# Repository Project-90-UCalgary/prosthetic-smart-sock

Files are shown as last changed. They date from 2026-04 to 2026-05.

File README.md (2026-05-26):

# prosthetic-smart-sock
Creating a smart sock for lower limb prosthetics to create more comfortable and constant fitting

## MATLAB 3D model

Run `MATLABWiFiV1.m` for the live GUI. The limb model is your CAD STL (`models/leg.stl`) with **16 sensors** on the calf sock patch. Change `SENSOR_SEED` to reshuffle sensor sites; replace `models/leg.stl` to update geometry.

## MindFuel Demo

See **`MindFuel Demo/`** for a self-contained demo package (ESP32 firmware, MATLAB GUI, wiring tutorial, and `models/leg.stl`).

## Setup

See `SETUP.md` for full replication steps (hardware, firmware, and MATLAB workflow).

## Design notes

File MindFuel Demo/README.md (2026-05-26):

# MindFuel Demo

Self-contained package for demonstrating the **Project 90 prosthetic smart sock** telemetry stack: 16-channel pressure sensing through a CD74HC4067 multiplexer, ESP32 firmware, and a MATLAB live visualization GUI with a 3D leg heatmap.

Part of the [prosthetic-smart-sock](https://github.com/Project-90-UCalgary/prosthetic-smart-sock) repository.

## What this iteration does

### Hardware

- **16 analog channels** (mux c0–c15) read through a **CD74HC4067** 16:1 analog multiplexer.
- **ESP32** selects mux channels, reads ADC values (12-bit, 0–4095), and exposes them to MATLAB.
- Typical sensor wiring: more mechanical pressure → **lower** ADC reading (FSR / divider style). The MATLAB GUI inverts this so **higher displayed values = more pressure**.

### Firmware (ESP32)

Two sketches are included under `firmware/`:

| Sketch | Use case |
|---|---|
| `ESP32_Wifi_Station_Test` | **Recommended for demos.** ESP32 joins Wi‑Fi (or starts SoftAP) and serves JSON at `/mux-all`. Built-in web dashboard at `/`. |
| `ESP32_Serial_Mux_16ch` | USB serial at **9600 baud** — one line per frame, 16 fixed-width ADC fields for MATLAB **Serial** mode. |

Both sketches share the same mux pin map (see `TUTORIAL.md`).

### MATLAB GUI (`matlab/MATLABWiFiV1.m`)

Run `runDemo` or `MATLABWiFiV1` from the `matlab/` folder.

The GUI provides:

- **3D heatmap** on a CAD leg mesh (`models/leg.stl`) with **16 sensor sites** on the calf/stump patch.
- **Live bar chart** and **10-second rolling history** for all 16 channels (M0–M15).
- **Dark theme** with light control sliders.
- **Four input modes:**
  1. **Random** — simulated signals for testing without hardware.
  2. **Sliders** — manual channel levels via on-screen sliders.
  3. **Serial** — live data from `ESP32_Serial_Mux_16ch` over USB.
  4. **WiFi AP (/mux-all)** — polls ESP32 JSON (default URL: `http://192.168.4.1/mux-all` when using SoftAP).

Heatmap behavior (current tuning):

- Local Gaussian blobs per sensor (`SIGMA_HEAT_MM = 20` mm).
- Max sensor value maps to the top of the color scale (yellow/white on the `hot` colormap).
- Fixed colorbar **0–100** with ticks at 0, 25, 50, 75, 100.

### Supporting files

| File | Role |
|---|---|
| `loadProstheticStlMesh.m` | Loads `leg.stl`, places 16 deterministic sensor sites along the stump axis. |
| `models/leg.stl` | Project 90 leg assembly mesh (mm units, native CAD orientation). |
| `runDemo.m` | Convenience launcher — changes to this folder and opens the GUI. |

## Quick start

1. Wire the mux and sensors (see **`TUTORIAL.md`**).
2. Flash **`firmware/ESP32_Wifi_Station_Test`** (set Wi‑Fi credentials or use SoftAP).
3. In MATLAB:
   ```matlab
   cd('MindFuel Demo/matlab')
   runDemo
   ```
4. Set **Input Mode** to **WiFi AP (/mux-all)** and confirm `WIFI_URL` in the script matches your ESP32 IP (e.g. `http://192.168.4.1/mux-all` for SoftAP).

For step-by-step wiring, flashing, and network setup, see **`TUTORIAL.md`**.

## Configuration knobs

In `MATLABWiFiV1.m` (top of file):

| Setting | Default | Purpose |
|---|---|---|
| `WIFI_URL` | `http://192.168.4.1/mux-all` | ESP32 JSON endpoint |
| `SENSOR_SEED` | `42` | Reproducible sensor placement on the mesh |
| `SIGMA_HEAT_MM` | `20` | Heat blob radius on the 3D surface |
| `SERIAL_INVERT_ADC` | `true` | Map lower ADC → higher display value |
| `CAL_ADC_MIN` / `CAL_ADC_MAX` | per-channel | Optional per-sensor calibration |

## Security note

Do **not** commit real Wi‑Fi passwords. Use placeholders in firmware and share credentials privately for demos.

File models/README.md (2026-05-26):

# Limb CAD mesh

- **`leg.stl`** — Project 90 prosthetic leg assembly (`May Prosthetic Assembyl.stl`), mm units.
- The loader keeps the **native CAD orientation** (no automatic re-rotation).
- To update: copy your export over this file, or set `LIMB_STL` in `MATLABWiFiV1.m`.

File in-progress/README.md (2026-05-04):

# In-progress (weekday work — not yet team-reviewed)

This folder holds **work-in-progress** versions of the GUI and ESP32 firmware. The **same paths at the repository root** and under `firmware/` stay on the **mainline / Saturday baseline** the team already agreed on.

| Path (mirrors repo) | Notes |
|---|---|
| `P90_Simulated_MLAB.m` | Weekday iteration: 5ch, 30s history, wall-clock axis, etc. |
| `ESP32_Wifi_Station_Test.ino` | Station + SoftAP + `/c1-c5` and related |
| `firmware/P90ArduinoMux.ino` | AP mode + serial + JSON |
| `firmware/ESP32_Wifi_Station_Test.ino` | |
| `firmware/README.txt` | |

**How to use:** Copy or diff these files over the root copies when promoting after Saturday sign-off, or run MATLAB/Arduino from this folder path until then.

**Do not** treat this tree as the default for new contributors — use root + `firmware/` for the stable project layout until the team merges the WIP.

## Weekly update log (in-progress)

GitHub’s README renderer usually **ignores** `<colgroup>` / `%` widths on HTML tables, so a two-column “Week & dates | Highlights” layout stays squeezed on the left. This section uses **headings + bullets** instead so dates stay on one line.

When you add a week: copy the `### …` block below, change the dates, and edit the highlights.

### Mon `2026-05-04`

**Highlights**

5 FSR channels; WiFi/JSON `c1`–`c5` + matching firmware; display 0–100; `turbo` colormap + linear heat scaling; 30 s history with **wall-clock** time axis; non-overlapping controls + more random-mode diversity; `in-progress/` split from mainline on GitHub.

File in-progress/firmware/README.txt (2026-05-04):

ESP32 sketches for P90 mux + WiFi JSON endpoints.

Before flashing: edit YOUR_* placeholders in the .ino files for SSID and password.
See repo root README.md for project context.

Included:
- P90ArduinoMux.ino — multiplexer scan + SoftAP + HTTP /c1-c4 (mux ch 1–4)
- ESP32_Wifi_Station_Test.ino — STA + SoftAP fallback + diagnostics

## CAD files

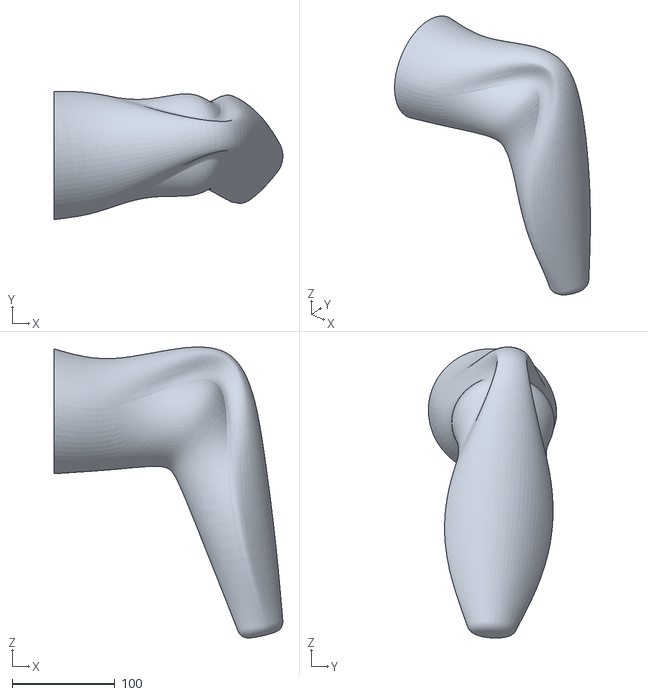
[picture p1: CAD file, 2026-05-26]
MindFuel Demo/matlab/models/leg.stl
223.0 x 125.0 x 283.8

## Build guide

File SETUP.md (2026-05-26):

# Project 90 Smart Sock Setup Guide

This guide explains how to set up the ESP32 firmware and MATLAB script so someone else can replicate the project.

## 1) Requirements

- ESP32 development board
- CD74HC4067 (16-channel analog multiplexer) or equivalent
- Pressure/analog sensors connected to the mux channels
- Jumper wires and breadboard
- USB cable for ESP32
- Arduino IDE (with ESP32 board support installed)
- MATLAB (for running the desktop-side script)
- A Wi-Fi network for STA mode (optional if using SoftAP fallback)

## 2) Wiring (based on current firmware constants)

The sketch `ESP32_Wifi_Station_Test.ino` currently uses:

- `LED_PIN = 4`
- `MUX_EN_PIN = 2`
- `MUX_S0_PIN = 12`
- `MUX_S1_PIN = 14`
- `MUX_S2_PIN = 27`
- `MUX_S3_PIN = 26`
- `MUX_SIG_PIN = 34` (ADC input)

Wire your mux select lines and signal output to these ESP32 pins, or update the constants in the sketch to match your hardware.

## 3) Configure and Flash ESP32 Firmware

1. Open `ESP32_Wifi_Station_Test.ino` in Arduino IDE.
2. Install required libraries if prompted (`WiFi.h` and `WebServer.h` come with ESP32 core).
3. Set network credentials before flashing:
   - `WIFI_SSID`
   - `WIFI_PASSWORD`
   - Optional AP fallback: `AP_SSID`, `AP_PASSWORD`
4. Select the correct ESP32 board and COM port.
5. Upload the sketch.
6. Open Serial Monitor at `115200` baud and confirm startup messages.

## 4) Validate ESP32 Server

After boot, the board will:

- Try to join Wi-Fi in station mode first.
- If station connection fails, start its own SoftAP network.

From a browser on the same network, open:

- `http://<esp32-ip>/` (dashboard)
- `http://<esp32-ip>/status`
- `http://<esp32-ip>/c0-c3`
- `http://<esp32-ip>/mux-all`

If using SoftAP fallback, connect your computer to the ESP32 AP SSID first, then use the AP IP shown in Serial Monitor.

## 5) Run MATLAB Integration

Primary script: **`MATLABWiFiV1.m`**

- 3D model: CAD assembly STL (`models/leg.stl`, copied from your export)
- **16 sensors** (mux c0–c15) placed randomly on the **calf sock patch** (mesh heuristic)
- Reshuffle sites: change `SENSOR_SEED` near the top of the script
- Replace mesh: overwrite `models/leg.stl` or set `LIMB_STL` in the script
- Loader: `loadProstheticStlMesh.m`

Legacy: `buildProstheticLimbMesh.m` (procedural fallback), `P90_Simulated_MLAB.m` (older GUI)

Typical workflow:

1. Open MATLAB and run `MATLABWiFiV1`.
2. Set `WIFI_URL` if using WiFi mode (ESP32 IP + `/mux-all`).
3. Confirm the 3D view shows 16 labeled points on the calf patch and live values update.

## 6) Security and Good Practices

- Do not commit real Wi-Fi passwords or personal hotspot credentials.
- Keep placeholders in committed code and share real credentials privately.
- If credentials were committed by mistake, rotate/change them immediately.

## 7) Troubleshooting

- No Wi-Fi connection:
  - Recheck SSID/password and signal strength.
  - Confirm 2.4 GHz support for ESP32 network.
- No sensor readings:
  - Verify mux wiring and ground reference.
  - Confirm `MUX_SIG_PIN` is connected to a valid ADC-capable pin.
- MATLAB cannot connect:
  - Confirm PC and ESP32 are on the same network.
  - Ping the ESP32 IP and test `/status` endpoint in browser first.

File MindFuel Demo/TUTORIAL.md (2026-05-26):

# MindFuel Demo — Connection Tutorial

This guide walks through wiring the hardware, flashing ESP32 firmware, and connecting the MATLAB GUI. No prior experience with the full repo is required if you start from this folder.

## Parts list

- ESP32 development board (USB data cable)
- CD74HC4067 (16-channel analog multiplexer) breakout or IC + breadboard
- Up to 16 analog pressure sensors (or potentiometers for bench testing)
- Jumper wires, common ground
- Computer with **Arduino IDE** (ESP32 board support) and **MATLAB**

## Step 1 — Understand the signal path

```
Sensor (c0..c15) → MUX common (SIG) → ESP32 ADC (GPIO 34)
ESP32 GPIO 2,12,14,27,26 → MUX EN, S0, S1, S2, S3
ESP32 → Wi‑Fi JSON  OR  USB serial  →  MATLAB GUI
```

Each mux channel is selected in turn; the ESP32 reads one ADC value per channel and sends all 16 to MATLAB.

## Step 2 — Wire the multiplexer

Use the pin map from the included firmware (both WiFi and Serial sketches):

| Signal | ESP32 GPIO | MUX pin (typical breakout label) |
|---|---|---|
| Enable | **2** | EN |
| Select S0 | **12** | S0 |
| Select S1 | **14** | S1 |
| Select S2 | **27** | S2 |
| Select S3 | **26** | S3 |
| Analog in | **34** | SIG (common output) |

Additional wiring:

- **VCC** — 3.3 V from ESP32 (or 5 V if your mux/sensors require it; keep ADC within ESP32 limits).
- **GND** — common ground between ESP32, mux, and all sensors.
- **Sensor outputs** — one sensor per mux channel **C0–C15** (sometimes labeled Y0–Y15 on breakouts).

Optional status LED (WiFi sketch only): **GPIO 4** → LED → resistor → GND.

> **Tip:** GPIO 34 is input-only and on ADC1, which works while Wi‑Fi is active on ESP32.

### Bench test without real sensors

Connect each mux channel to a **potentiometer** (wiper → channel, ends → 3.3 V and GND) or leave channels floating to verify the GUI responds.

## Step 3 — Choose firmware path

### Option A — WiFi (best for live demos)

1. Open `firmware/ESP32_Wifi_Station_Test/ESP32_Wifi_Station_Test.ino` in Arduino IDE.
2. Edit credentials at the top of the file:
   ```cpp
   const char* WIFI_SSID = "YOUR_WIFI_SSID";
   const char* WIFI_PASSWORD = "YOUR_WIFI_PASSWORD";
   ```
   SoftAP fallback (if STA fails):
   ```cpp
   const char* AP_SSID = "P90-ESP32-MUX";
   const char* AP_PASSWORD = "CHANGE_ME_AP_PASSWORD";
   ```
3. **Tools → Board** — select your ESP32 board.
4. **Tools → Port** — select the USB COM port.
5. **Upload** the sketch.
6. Open **Serial Monitor** at **115200 baud** and note the IP address printed at boot.

**Verify in a browser** (same network as ESP32, or connected to ESP32 SoftAP):

- Dashboard: `http://<esp32-ip>/`
- All channels JSON: `http://<esp32-ip>/mux-all`
- Status: `http://<esp32-ip>/status`

Example `/mux-all` response:
```json
{"c0":1234,"c1":1180,...,"c15":990}
```

### Option B — USB Serial

1. Open `firmware/ESP32_Serial_Mux_16ch/ESP32_Serial_Mux_16ch.ino`.
2. Upload to ESP32 (same board/port as above).
3. Serial output is **9600 baud**, one line per frame:
   ```
        1234  1180  1150 ... (16 six-character fields) 
   ```
4. Close Arduino Serial Monitor before opening MATLAB (only one program can use the COM port).

## Step 4 — Connect MATLAB

1. Open MATLAB.
2. Go to the demo MATLAB folder:
   ```matlab
   cd('MindFuel Demo/matlab')   % adjust path if needed
   runDemo
   ```
   Or run `MATLABWiFiV1` directly.

3. In the **Controls** panel, pick an **Input Mode**:

   | Mode | When to use |
   |------|-------------|
   | Random | No hardware — test charts and 3D heatmap |
   | Sliders | Manual demo — drag M0–M15 sliders |
   | Serial (c0–c15) | ESP32 running **ESP32_Serial_Mux_16ch** |
   | WiFi AP (/mux-all) | ESP32 running **ESP32_Wifi_Station_Test** |

### WiFi mode setup

1. If ESP32 uses **SoftAP**, connect your PC to the ESP32 Wi‑Fi network (`P90-ESP32-MUX` by default).
2. In `MATLABWiFiV1.m`, set `WIFI_URL` near the top to match your ESP32:
   ```matlab
   WIFI_URL = "http://192.168.4.1/mux-all";   % typical SoftAP address
   ```
   For station mode, use the IP from Serial Monitor, e.g. `"http://192.168.1.42/mux-all"`.
3. Select **WiFi AP (/mux-all)** in the GUI dropdown.

### Serial mode setup

1. Flash **ESP32_Serial_Mux_16ch**.
2. In the GUI, select **Serial (c0–c15)**.
3. Choose the correct **COM port** (click **Refresh ports** if needed).
4. Close Arduino Serial Monitor if the port is busy.

## Step 5 — Confirm it is working

You should see:

- **Live Values** bars moving for M0–M15.
- **History** lines updating over the last 10 seconds.
- **3D heatmap** on the leg model with colored blobs near active sensors.
- Sensor labels **M0–M15** on the mesh surface.

Press a sensor (or turn a test potentiometer): the corresponding bar and heat spot should rise. With default settings, **more pressure → higher bar value** (ADC is inverted in software).

## Troubleshooting

| Problem | Things to check |
|---|---|
| No WiFi connection | SSID/password, 2.4 GHz network, Serial Monitor boot log |
| Browser can't reach `/mux-all` | PC on same network (or on ESP32 SoftAP); correct IP |
| MATLAB WiFi mode flatlines | `WIFI_URL` matches ESP32 IP; test URL in browser first |
| Serial mode no data | Correct COM port; 9600 baud sketch; Serial Monitor closed |
| Values inverted | Toggle `SERIAL_INVERT_ADC` in `MATLABWiFiV1.m` |
| Wrong channel order | Mux S0–S3 wiring; sensor on expected Cn pin |
| Port access denied | Close Arduino IDE Serial Monitor and other serial tools |

## Demo tips (MindFuel / presentation)

1. Start in **Random** or **Sliders** mode to show the GUI before plugging in hardware.
2. Switch to **WiFi** for a cable-free demo — audience can also open the ESP32 dashboard on a phone.
3. Rotate the 3D leg with **left-click drag** on the heatmap panel.
4. Adjust **Smoothing (EMA α)** if live traces look too noisy or too sluggish.

## Next steps

- Per-sensor calibration: edit `CAL_ADC_MIN` and `CAL_ADC_MAX` in `MATLABWiFiV1.m`.
- Reshuffle sensor positions on the mesh: change `SENSOR_SEED`.
- Replace geometry: overwrite `matlab/models/leg.stl`.

For repository-wide context, see the root [README.md](../README.md) and [SETUP.md](../SETUP.md).

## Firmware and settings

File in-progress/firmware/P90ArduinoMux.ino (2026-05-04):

// ESP32 WiFi AP + HTTP server for MUX ch 1–5 (JSON c1–c5; legacy /c1-c4 unchanged)
#include <WiFi.h>
#include <WebServer.h>

int EN = 2;
int S0 = 12;
int S1 = 14;
int S2 = 27;
int S3 = 26;
// With WiFi enabled on ESP32, ADC2 pins (like GPIO13) can read as zero.
// Use ADC1 for the mux signal input.
const int MUX_SIG_PIN = 34; // GPIO34 (ADC1, input-only)

// --- WiFi AP config (change as needed) ---
// Set these before flashing (do not commit real secrets to public repos).
const char* AP_SSID = "YOUR_AP_SSID";
const char* AP_PASSWORD = "YOUR_AP_PASSWORD";

WebServer server(80);
bool apStarted = false;
int lastStationCount = -1;
const int STATUS_LED_PIN = 2; // Built-in LED on many ESP32 boards

// Format to print
char padded[12];

// MUX select bits
void out0()
{
  digitalWrite (EN, LOW);
  digitalWrite (S0, LOW);
  digitalWrite (S1, LOW);
  digitalWrite (S2, LOW);
  digitalWrite (S3, LOW);
}
void out1()
{
  digitalWrite (EN, LOW);
  digitalWrite (S0, HIGH);
  digitalWrite (S1, LOW);
  digitalWrite (S2, LOW);
  digitalWrite (S3, LOW);
}
void out2()
{
  digitalWrite (EN, LOW);
  digitalWrite (S0, LOW);
  digitalWrite (S1, HIGH);
  digitalWrite (S2, LOW);
  digitalWrite (S3, LOW);
}
void out3()
{
  digitalWrite (EN, LOW);
  digitalWrite (S0, HIGH);
  digitalWrite (S1, HIGH);
  digitalWrite (S2, LOW);
  digitalWrite (S3, LOW);
}
void out4()
{
  digitalWrite (EN, LOW);
  digitalWrite (S0, LOW);
  digitalWrite (S1, LOW);
  digitalWrite (S2, HIGH);
  digitalWrite (S3, LOW);
}
void out5()
{
  digitalWrite (EN, LOW);
  digitalWrite (S0, HIGH);
  digitalWrite (S1, LOW);
  digitalWrite (S2, HIGH);
  digitalWrite (S3, LOW);
}
void out6()
{
  digitalWrite (EN, LOW);
  digitalWrite (S0, LOW);
  digitalWrite (S1, HIGH);
  digitalWrite (S2, HIGH);
  digitalWrite (S3, LOW);
}
void out7()
{
  digitalWrite (EN, LOW);
  digitalWrite (S0, HIGH);
  digitalWrite (S1, HIGH);
  digitalWrite (S2, HIGH);
  digitalWrite (S3, LOW);
}
void out8()
{
  digitalWrite (EN, LOW);
  digitalWrite (S0, LOW);
  digitalWrite (S1, LOW);
  digitalWrite (S2, LOW);
  digitalWrite (S3, HIGH);
}
void out9()
{
  digitalWrite (EN, LOW);
  digitalWrite (S0, HIGH);
  digitalWrite (S1, LOW);
  digitalWrite (S2, LOW);
  digitalWrite (S3, HIGH);
}
void out10()
{
  digitalWrite (EN, LOW);
  digitalWrite (S0, LOW);
  digitalWrite (S1, HIGH);
  digitalWrite (S2, LOW);
  digitalWrite (S3, HIGH);
}
void out11()
{
  digitalWrite (EN, LOW);
  digitalWrite (S0, HIGH);
  digitalWrite (S1, HIGH);
  digitalWrite (S2, LOW);
  digitalWrite (S3, HIGH);
}
void out12()
{
  digitalWrite (EN, LOW);
  digitalWrite (S0, LOW);
  digitalWrite (S1, LOW);
  digitalWrite (S2, HIGH);
  digitalWrite (S3, HIGH);
}
void out13()
{
  digitalWrite (EN, LOW);
  digitalWrite (S0, HIGH);
  digitalWrite (S1, LOW);
  digitalWrite (S2, HIGH);
  digitalWrite (S3, HIGH);
}
void out14()
{
  digitalWrite (EN, LOW);
  digitalWrite (S0, LOW);
  digitalWrite (S1, HIGH);
  digitalWrite (S2, HIGH);
  digitalWrite (S3, HIGH);
}
void out15()
{
  digitalWrite (EN, LOW);
  digitalWrite (S0, HIGH);
  digitalWrite (S1, HIGH);
  digitalWrite (S2, HIGH);
  digitalWrite (S3, HIGH);
}
// Bypass mux
void bypass()
{
  digitalWrite (EN, HIGH);
}

void select_mux_pin(int i)
{
  switch (i) {
    case 0: 
      out0();
      break;
    case 1:
      out1();
      break;
    case 2:
      out2();
      break;
    case 3:
      out3();
      break;
    case 4:
      out4();
      break;
    case 5:
      out5();
      break;
    case 6:
      out6();
      break;
    case 7:
      out7();
      break;
    case 8:
      out8();
      break;
    case 9:
      out9();
      break;
    case 10:
      out10();
      break;
    case 11:
      out11();
      break;
    case 12:
      out12();
      break;
    case 13:
      out13();
      break;
    case 14:
      out14();
      break;
    case 15:
      out15();
      break;
    default:
      bypass();
      break;
  }
}

String readC1ToC4Json()
{
  int values[4];

  for (int i = 0; i < 4; i++) {
    int ch = i + 1;
    select_mux_pin(ch);
    delayMicroseconds(100);
    values[i] = analogRead(MUX_SIG_PIN);
  }

  char payload[96];
  snprintf(
    payload,
    sizeof(payload),
    "{\"c1\":%d,\"c2\":%d,\"c3\":%d,\"c4\":%d}",
    values[0], values[1], values[2], values[3]
  );
  return String(payload);
}

// Five FSR / mux channels (ch 1..5) for mLab
String readC1ToC5Json()
{
  const int N = 5;
  int values[5];

  for (int i = 0; i < N; i++) {
    int ch = i + 1;
    select_mux_pin(ch);
    delayMicroseconds(100);
    values[i] = analogRead(MUX_SIG_PIN);
  }

  char payload[120];
  snprintf(
    payload,
    sizeof(payload),
    "{\"c1\":%d,\"c2\":%d,\"c3\":%d,\"c4\":%d,\"c5\":%d}",
    values[0], values[1], values[2], values[3], values[4]
  );
  return String(payload);
}

void handleRoot()
{
  server.send(200, "text/plain", "P90 MUX AP online. Use /c1-c5 for JSON (mux ch 1–5) or /c1-c4 (legacy).");
}

void handleC1ToC4()
{
  server.send(200, "application/json", readC1ToC4Json());
}

void handleC1ToC5()
{
  server.send(200, "application/json", readC1ToC5Json());
}

void handleWifiStatus()
{
  int stations = WiFi.softAPgetStationNum();
  char payload[160];
  snprintf(
    payload,
    sizeof(payload),
    "{\"apStarted\":%s,\"ssid\":\"%s\",\"ip\":\"%s\",\"stations\":%d}",
    apStarted ? "true" : "false",
    AP_SSID,
    WiFi.softAPIP().toString().c_str(),
    stations
  );
  server.send(200, "application/json", payload);
}

void setup()
{
  // Open serial + set pins
  Serial.begin (9600);
  pinMode (STATUS_LED_PIN, OUTPUT);
  digitalWrite(STATUS_LED_PIN, LOW);
  pinMode (EN, OUTPUT);
  pinMode (S0, OUTPUT);
  pinMode (S1, OUTPUT);
  pinMode (S2, OUTPUT);
  pinMode (S3, OUTPUT);

  // Start local AP so mLab script can connect directly
  WiFi.mode(WIFI_AP);
  apStarted = WiFi.softAP(AP_SSID, AP_PASSWORD);

  server.on("/", handleRoot);
  server.on("/c1-c4", HTTP_GET, handleC1ToC4);
  server.on("/c1-c5", HTTP_GET, handleC1ToC5);
  server.on("/wifi-status", HTTP_GET, handleWifiStatus);
  server.begin();

  if (apStarted) {
    digitalWrite(STATUS_LED_PIN, HIGH); // steady ON = AP started
    Serial.println("WiFi AP STARTED");
    Serial.print("AP SSID: ");
    Serial.println(AP_SSID);
    Serial.print("AP IP: ");
    Serial.println(WiFi.softAPIP());
    Serial.println("Open http://192.168.4.1/wifi-status or /c1-c5 to verify.");
  } else {
    digitalWrite(STATUS_LED_PIN, LOW);
    Serial.println("WiFi AP FAILED TO START");
  }
}

void loop() {
  server.handleClient();

  // Blink LED when at least one client is connected to AP.
  int stations = WiFi.softAPgetStationNum();
  if (apStarted) {
    if (stations > 0) {
      digitalWrite(STATUS_LED_PIN, (millis() / 250) % 2);
    } else {
      digitalWrite(STATUS_LED_PIN, HIGH); // AP up, no clients
    }
  } else {
    digitalWrite(STATUS_LED_PIN, LOW);
  }

  if (stations != lastStationCount) {
    Serial.print("AP connected clients: ");
    Serial.println(stations);
    lastStationCount = stations;
  }
  
  for (int i = 0; i < 16; i++) {
    // Select input
    select_mux_pin(i);
    // Read from sensor
    int sensor_value = analogRead(MUX_SIG_PIN);
    // int sensor_value1 = analogRead(A1);
    // Read from A0 and place value into array for formatting
    sprintf(padded, "%6d", sensor_value); // ex "  123"
    //sprintf(padded, "%6d", sensor_value1);
    // Format
    if (i == 15) {
      Serial.println(padded); // new line
      break; // reset loop
    }
    else
      Serial.print(padded);
      
    // Timing (test and modify)
    delay(1); // 1ms
  }
}

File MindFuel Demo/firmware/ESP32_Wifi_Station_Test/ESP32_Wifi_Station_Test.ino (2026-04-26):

/*
  ESP32 WiFi + MUX server
  - Tries STA (join existing WiFi) first
  - Falls back to SoftAP (ESP32 creates its own network)
  - Hosts /status, /c0-c3 and /mux-all JSON endpoints
  - Hosts a live dashboard at /
*/

#include <WiFi.h>
#include <WebServer.h>

// STA credentials (ESP32 tries this first)
// Set these locally before flashing; do not commit real values.
const char* WIFI_SSID = "YOUR_WIFI_SSID";
const char* WIFI_PASSWORD = "YOUR_WIFI_PASSWORD";

// SoftAP fallback credentials
const char* AP_SSID = "P90-ESP32-MUX";
const char* AP_PASSWORD = "CHANGE_ME_AP_PASSWORD";

WebServer server(80);

const int LED_PIN = 4; // External/status LED pin (kept separate from mux EN)
const int MUX_EN_PIN = 2;
const int MUX_S0_PIN = 12;
const int MUX_S1_PIN = 14;
const int MUX_S2_PIN = 27;
const int MUX_S3_PIN = 26;
const int MUX_SIG_PIN = 34; // ADC1 input, works with WiFi active

unsigned long lastBlinkMs = 0;
bool ledState = false;
bool staConnected = false;
bool apStarted = false;

String activeIP() {
  if (staConnected) return WiFi.localIP().toString();
  if (apStarted) return WiFi.softAPIP().toString();
  return "0.0.0.0";
}

void handleRoot() {
  const char* page = R"HTML(
<!doctype html>
<html>
<head>
  <meta charset="utf-8">
  <meta name="viewport" content="width=device-width,initial-scale=1">
  <title>ESP32 MUX Dashboard</title>
  <style>
    body { font-family: Arial, sans-serif; margin: 20px; background:#111; color:#eee; }
    .card { background:#1b1b1b; border:1px solid #333; border-radius:10px; padding:14px; margin-bottom:14px; }
    .row { display:flex; gap:10px; flex-wrap:wrap; }
    .chip { background:#222; border:1px solid #3a3a3a; padding:8px 12px; border-radius:999px; }
    .grid { display:grid; grid-template-columns: repeat(4, minmax(100px, 1fr)); gap:8px; }
    .cell { background:#1f1f1f; border:1px solid #333; border-radius:8px; padding:8px; }
    .k { color:#9ecbff; font-size:12px; }
    .v { font-size:20px; font-weight:bold; }
    a { color:#9ecbff; }
  </style>
</head>
<body>
  <h2>ESP32 MUX Dashboard</h2>
  <div class="card">
    <div class="row" id="statusRow">
      <div class="chip">Loading status...</div>
    </div>
  </div>
  <div class="card">
    <div class="grid" id="muxGrid"></div>
  </div>
  <div class="card">
    Endpoints:
    <a href="/status" target="_blank">/status</a>,
    <a href="/c0-c3" target="_blank">/c0-c3</a>,
    <a href="/mux-all" target="_blank">/mux-all</a>
  </div>
  <script>
    function renderStatus(s) {
      const row = document.getElementById('statusRow');
      row.innerHTML = '';
      const items = [
        ['mode', s.mode],
        ['ssid', s.ssid],
        ['ip', s.ip],
        ['rssi', s.rssi],
        ['stations', s.stations]
      ];
      for (const [k, v] of items) {
        const d = document.createElement('div');
        d.className = 'chip';
        d.textContent = k + ': ' + v;
        row.appendChild(d);
      }
    }

    function renderMux(m) {
      const grid = document.getElementById('muxGrid');
      grid.innerHTML = '';
      for (let i = 0; i < 16; i++) {
        const key = 'c' + i;
        const cell = document.createElement('div');
        cell.className = 'cell';
        cell.innerHTML = '<div class="k">' + key.toUpperCase() + '</div><div class="v">' + (m[key] ?? '-') + '</div>';
        grid.appendChild(cell);
      }
    }

    async function tick() {
      try {
        const [sRes, mRes] = await Promise.all([fetch('/status'), fetch('/mux-all')]);
        renderStatus(await sRes.json());
        renderMux(await mRes.json());
      } catch (e) {}
    }
    tick();
    setInterval(tick, 500);
  </script>
</body>
</html>
  )HTML";
  server.send(200, "text/html", page);
}

void handleStatus() {
  String body = "{";
  body += "\"connected\":";
  body += (staConnected || apStarted) ? "true" : "false";
  body += ",\"mode\":\"";
  body += staConnected ? "sta" : (apStarted ? "ap" : "none");
  body += "\"";
  body += ",\"ssid\":\"";
  body += staConnected ? WiFi.SSID() : (apStarted ? String(AP_SSID) : "");
  body += "\"";
  body += ",\"ip\":\"" + activeIP() + "\"";
  body += ",\"rssi\":";
  body += staConnected ? String(WiFi.RSSI()) : String(0);
  body += ",\"stations\":";
  body += apStarted ? String(WiFi.softAPgetStationNum()) : String(0);
  body += "}";
  server.send(200, "application/json", body);
}

void selectMuxChannel(int channel) {
  if (channel < 0 || channel > 15) {
    digitalWrite(MUX_EN_PIN, HIGH); // disable mux on invalid input
    return;
  }

  digitalWrite(MUX_EN_PIN, LOW); // enable mux
  digitalWrite(MUX_S0_PIN, (channel & 0x01) ? HIGH : LOW);
  digitalWrite(MUX_S1_PIN, (channel & 0x02) ? HIGH : LOW);
  digitalWrite(MUX_S2_PIN, (channel & 0x04) ? HIGH : LOW);
  digitalWrite(MUX_S3_PIN, (channel & 0x08) ? HIGH : LOW);
}

int readMuxChannel(int channel) {
  selectMuxChannel(channel);
  delayMicroseconds(120); // settle time after channel switch
  return analogRead(MUX_SIG_PIN);
}

void handleC0ToC3() {
  int c0 = readMuxChannel(0);
  int c1 = readMuxChannel(1);
  int c2 = readMuxChannel(2);
  int c3 = readMuxChannel(3);

  char payload[96];
  snprintf(
    payload,
    sizeof(payload),
    "{\"c0\":%d,\"c1\":%d,\"c2\":%d,\"c3\":%d}",
    c0, c1, c2, c3
  );
  server.send(200, "application/json", payload);
}

void handleMuxAll() {
  String payload = "{";
  for (int i = 0; i < 16; i++) {
    payload += "\"c";
    payload += i;
    payload += "\":";
    payload += readMuxChannel(i);
    if (i < 15) payload += ",";
  }
  payload += "}";
  server.send(200, "application/json", payload);
}

void printWifiInfo() {
  Serial.println();
  Serial.println("=== WIFI STATUS ===");
  Serial.print("WiFi.status(): ");
  Serial.println(WiFi.status());
  Serial.print("Connected SSID: ");
  Serial.println(WiFi.SSID());
  Serial.print("Local IP: ");
  Serial.println(WiFi.localIP());
  Serial.print("Gateway: ");
  Serial.println(WiFi.gatewayIP());
  Serial.print("Subnet: ");
  Serial.println(WiFi.subnetMask());
  Serial.print("DNS: ");
  Serial.println(WiFi.dnsIP());
  Serial.print("RSSI (dBm): ");
  Serial.println(WiFi.RSSI());
  Serial.println("===================");
}

bool connectWifi(unsigned long timeoutMs) {
  WiFi.mode(WIFI_STA);
  WiFi.disconnect(true, true);
  delay(300);

  Serial.print("Connecting to SSID: ");
  Serial.println(WIFI_SSID);
  WiFi.begin(WIFI_SSID, WIFI_PASSWORD);

  unsigned long t0 = millis();
  while (WiFi.status() != WL_CONNECTED && (millis() - t0) < timeoutMs) {
    Serial.print(".");
    delay(300);
  }
  Serial.println();

  if (WiFi.status() == WL_CONNECTED) {
    Serial.println("WiFi CONNECTED");
    printWifiInfo();
    return true;
  }

  Serial.println("WiFi FAILED to connect within timeout");
  printWifiInfo();
  return false;
}
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

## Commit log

2026-03-28 Add MATLAB GUI and Arduino 2-mux sketch for prosthetic smart sock
2026-04-26 Add sanitized ESP32 WiFi station test sketch.
    Made-with: Cursor
2026-04-26 Add project setup guide for replication.
    Document hardware wiring, firmware upload, endpoint checks, MATLAB workflow, and troubleshooting so new contributors can reproduce the setup quickly.
    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
2026-05-02 Add ESP32 WiFi firmware and update MATLAB GUI (WiFi + serial modes).
    Includes firmware/P90ArduinoMux.ino and ESP32_Wifi_Station_Test.ino with placeholder WiFi credentials. Move legacy mux sketch into Arduino-style folder. Refresh P90_Simulated_MLAB.m.
2026-05-04 P90 GUI: 5ch, 30s history, wall-clock axis, FSR layout, colormap, WiFi c1-c5
    MATLAB: NCH=5, YMAX 0-100, turbo colormap, linear heat gain, 30s window with wall-clock x-axis and fixed xlim, random per-channel variation, non-overlapping controls. Firmware: c1-c5 JSON endpoints, station tests updated.
    [ESP32_Wifi_Station_Test.ino, P90ArduinoMux.ino]
2026-05-04 Update FSR labeling and slider range in MATLAB views.
    Align 3D sensor naming to FSR labels in the in-progress GUI and raise the root GUI slider/display scale to 0-100 while using fsr_* point variables in the heatmap path.
2026-05-26 Add MindFuel Demo package and 16-channel STL telemetry GUI.
    Bundle ESP32 firmware, MATLAB scripts, leg mesh, and setup docs so demos can run from one folder, and update the main GUI for 16-channel CAD heatmaps with dark theme.
    [leg.stl]
